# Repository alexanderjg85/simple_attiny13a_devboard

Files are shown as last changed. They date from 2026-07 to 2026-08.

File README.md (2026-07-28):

# simple_attiny13a_devboard
A simple development board with an LED and GPIOs on Pin header, includes also ISP Header, Power supply with screw terminal.

## Project Structure
- **/hardware**: Contains the KiCad schematic and PCB layout files.
- **/firmware**: Contains the Microchip Studio 7 C/ASM source code.

## Programming Notes
- Designed for the **ATtiny13A** microcontroller.
- Programmed using **Atmel Studio 7** and an **AVRISP mkII** programmer.
- *Note:* The board requires an external power supply (e.g., 5V) during programming, as the AVRISP mkII does not supply power to the target VCC.

## License / Lizenz

This project is dual-licensed / Dieses Projekt ist dual-lizenziert:

* **Hardware (Schematic, PCB Layout):** Licensed under the [CERN Open Hardware Licence Version 2 - Permissive (CERN-OHL-P)](LICENSE_HARDWARE.md).
* **Software (Firmware, Example Code):** Licensed under the [MIT License](LICENSE).

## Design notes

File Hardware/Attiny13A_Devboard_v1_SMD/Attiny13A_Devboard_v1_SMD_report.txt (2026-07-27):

PCB statistics report
=====================
- Date: Mon 27 Jul 2026 23:36:47 CEST
- Project: Attiny13A_Devboard_v1_SMD
- Board name: Attiny13A_Devboard_v1_SMD

Board
-----
- Width: 48.0000 mm
- Height: 24.0000 mm
- Area: 1152.00 mm²
- Front copper area: 191.524 mm²
- Back copper area: 1065.117 mm²
- Min track clearance: 0.2000 mm
- Min track width: 0.3000 mm
- Min drill diameter: 0.4500 mm
- Board stackup thickness: 1.6000 mm

- Front footprint area: 438.677 mm²
- Back footprint area: 58.296 mm²
- Front component density: 38.08 %
- Back component density: 5.06 %
Pads
----
- Through hole: 14
- SMD: 33
- Connector: 0
- NPTH: 0
- Castellated: 0
- Press-fit: 0

Vias
----
- Through vias: 19
- Blind vias: 0
- Buried vias: 0
- Micro vias: 0

Components
----------

| | Front Side | Back Side | Total |
|---|---|---|---|
|THT: | 3 | 0 | 3 |
|SMD: | 8 | 0 | 8 |
|Unspecified:  | 9 | 0 | 9 |
|Total: | 20 | 0 | 20 |

Drill holes
-----------

| Count | Shape | X Size | Y Size | Plated | Via/Pad | Start Layer | Stop Layer |
|---|---|---|---|---|---|---|---|
| 12 | Round | 1.0000 mm | 1.0000 mm | PTH | Pad | F.Cu | B.Cu |
| 11 | Round | 0.5000 mm | 0.5000 mm | PTH | Via | F.Cu | B.Cu |
| 8 | Round | 0.4500 mm | 0.4500 mm | PTH | Via | F.Cu | B.Cu |
| 2 | Round | 1.3000 mm | 1.3000 mm | PTH | Pad | F.Cu | B.Cu |

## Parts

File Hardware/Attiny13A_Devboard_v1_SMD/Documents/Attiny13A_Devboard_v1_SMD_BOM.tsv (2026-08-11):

Reference | Qty | Value | Spec | Package | MFR PN
C1 | 1 | 10 uF | 20% 16V | 1206
C2 | 1 | 100 nF | 20% 16V | 1206
D1 | 1 | SS14 | 0.5A 30 V | SMA
D2 | 1 | RED | LED RED | 1206
J1 | 1 | Screw_Terminal_01x02 | Horizontal | 5.08mm 1x2
J2 | 1 | ISP-6 | Male / THT/ Vertical | 2.54 mm 1x3
J3 | 1 | Conn_01x06_Pin | Male / THT/ Vertical | 2.54 mm 1x6
R1 | 1 | 470 | 1% 125 mW | 1206
R2 | 1 | 10k | 1% 125 mW | 1206
SW1 | 1 | SW_RESET | H=4.5mm Tactile | 4.5 x 4.5 SMD | SWT0210-045026GSA
U1 | 1 | ATtiny13A-SS | 8-Bit AVR 20 Mhz | SOIC-8 | ATTINY13A-SSU

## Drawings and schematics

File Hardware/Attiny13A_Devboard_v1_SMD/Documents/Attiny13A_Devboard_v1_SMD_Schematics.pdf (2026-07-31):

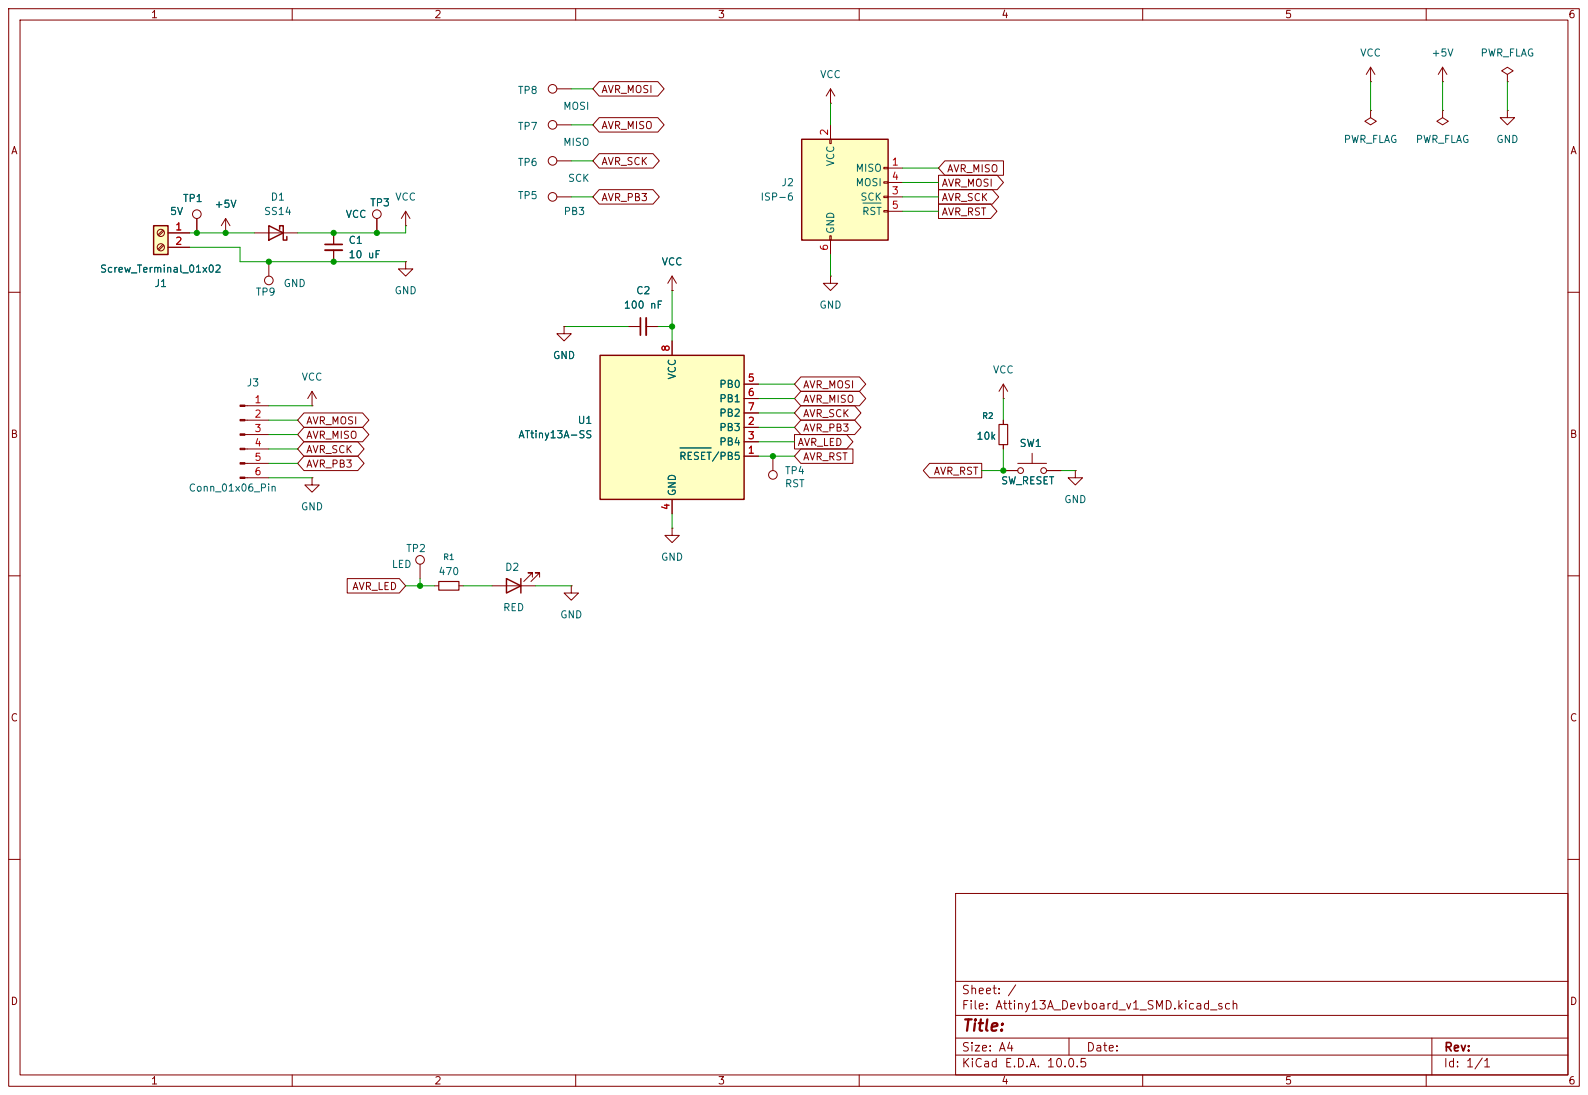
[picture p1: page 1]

Size: A4 | Rev:
KiCad E.D.A. 10.0.5 | Id: 1/1

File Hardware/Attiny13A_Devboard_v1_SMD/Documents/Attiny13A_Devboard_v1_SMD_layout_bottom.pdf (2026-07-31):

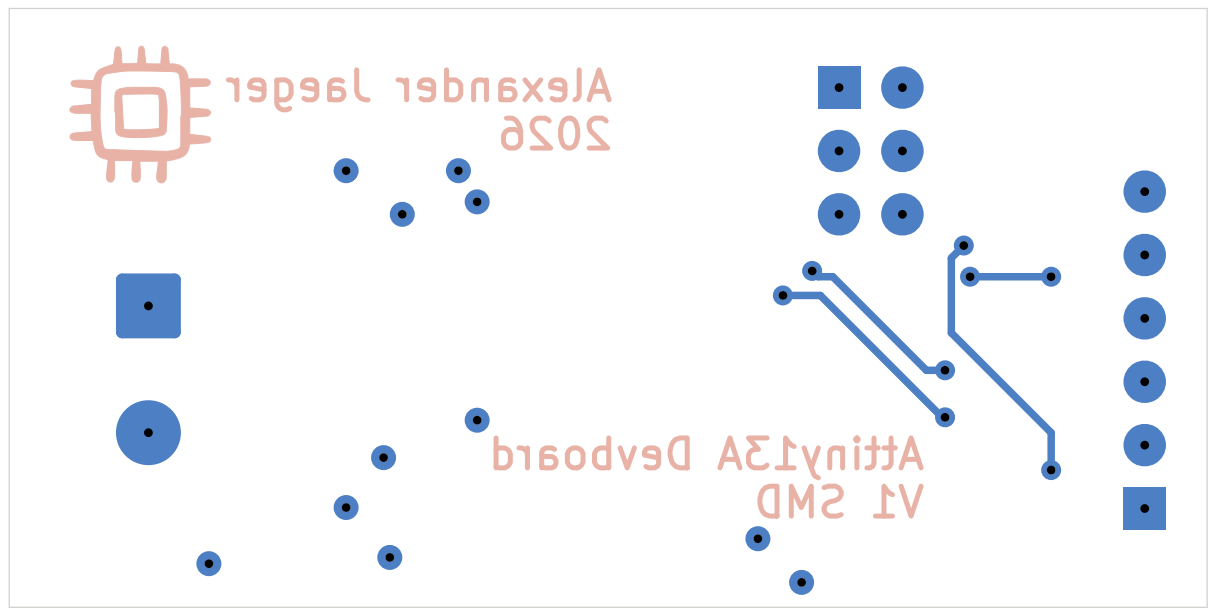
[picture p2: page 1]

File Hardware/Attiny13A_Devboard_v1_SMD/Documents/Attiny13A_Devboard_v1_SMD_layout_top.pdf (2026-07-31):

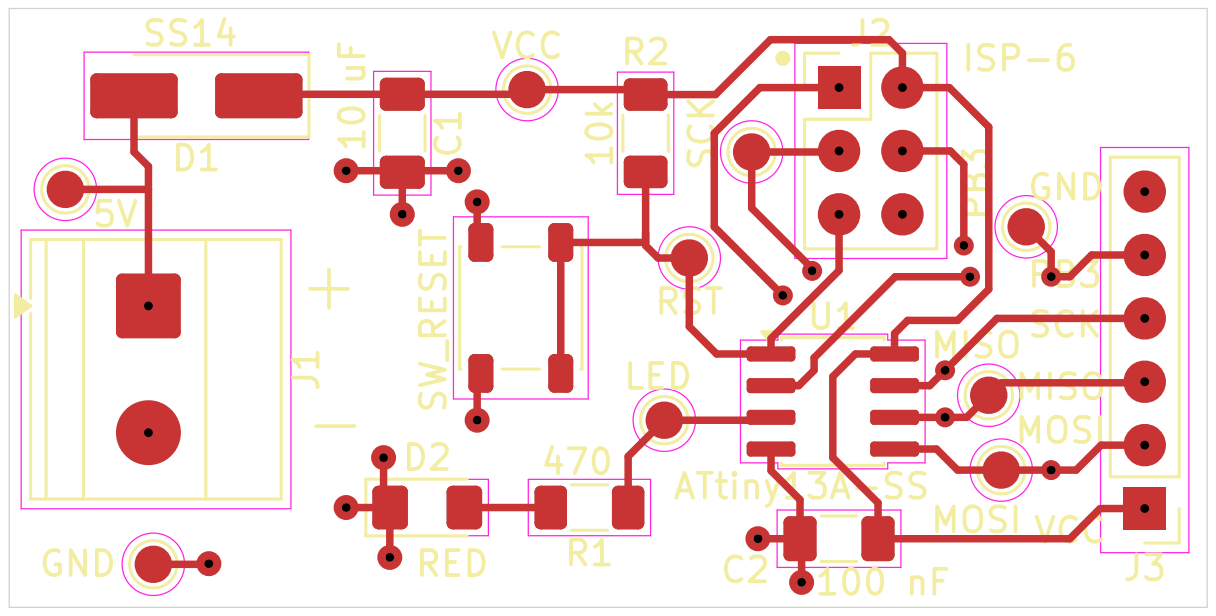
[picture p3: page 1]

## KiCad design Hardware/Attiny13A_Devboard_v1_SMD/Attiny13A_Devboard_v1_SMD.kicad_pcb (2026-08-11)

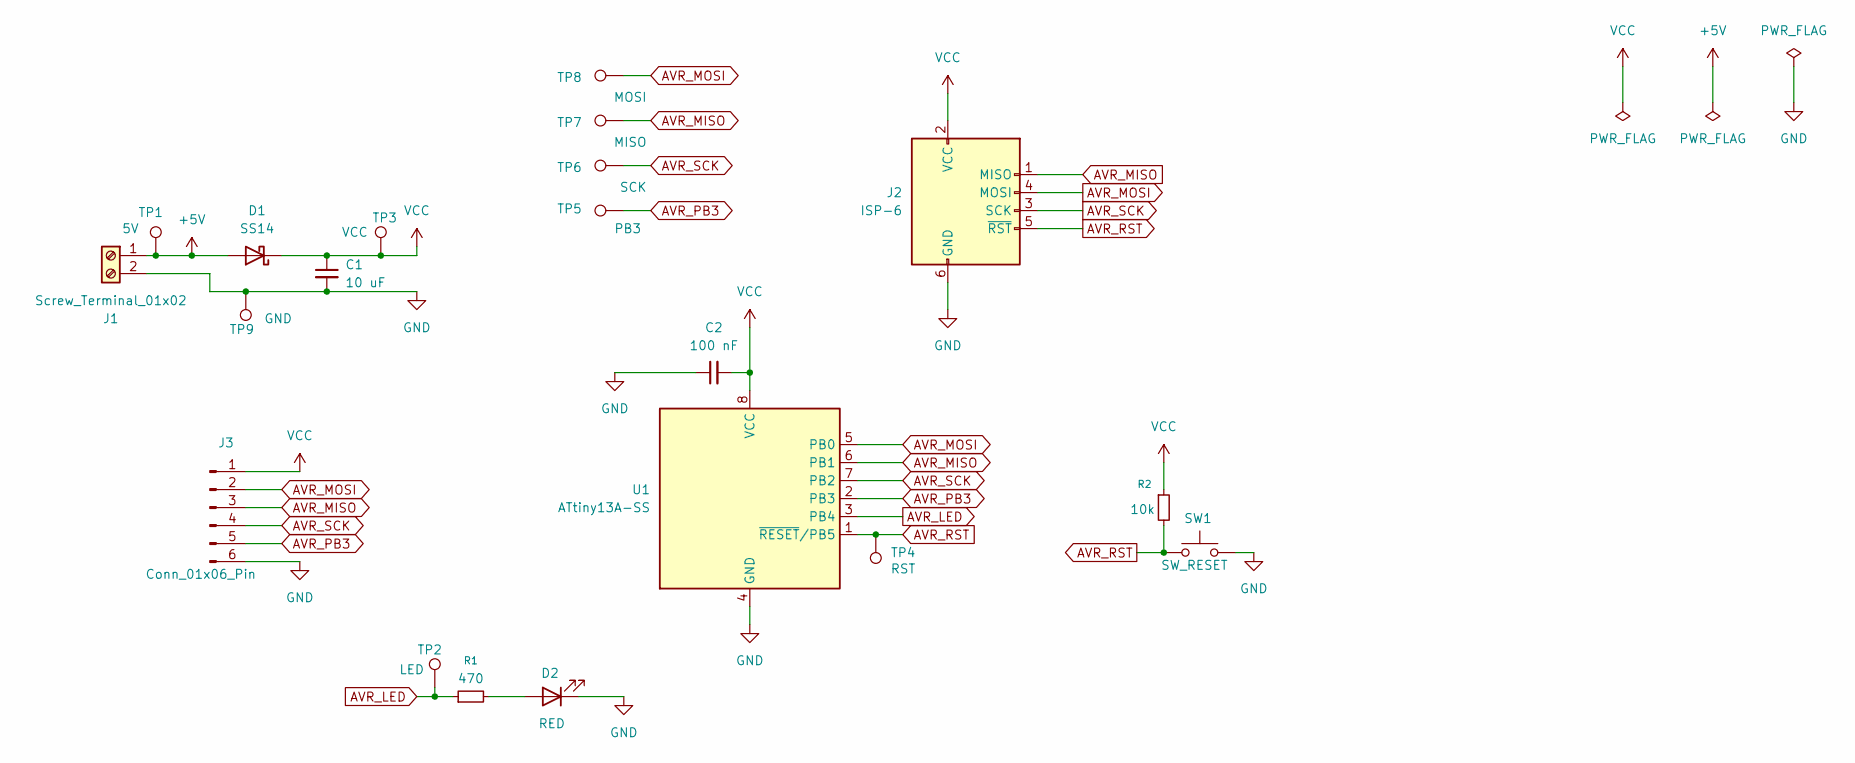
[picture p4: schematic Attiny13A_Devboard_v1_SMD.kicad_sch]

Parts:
C1: 10 uF; C_1206_3216Metric_Pad1.33x1.80mm_HandSolder
C2: 100 nF; C_1206_3216Metric_Pad1.33x1.80mm_HandSolder
D1: SS14; D_SMA_Handsoldering
D2: RED; LED_1206_3216Metric_Pad1.42x1.75mm_HandSolder
J1: Screw_Terminal_01x02; TerminalBlock_Phoenix_MKDS-1,5-2-5.08_1x02_P5.08mm_Horizont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
J2: ISP-6; PinHeader_2x03_P2.54mm_Vertical
J3: Conn_01x06_Pin; PinHeader_1x06_P2.54mm_Vertical
R1: 470; R_1206_3216Metric_Pad1.30x1.75mm_HandSolder
R2: 10k; R_1206_3216Metric_Pad1.30x1.75mm_HandSolder
SW1: SW_RESET; SW_SPST_PTS647_Sx38_Handsolder; MFR PN SWT0210-045026GSA
TP1: 5V; TestPoint_Pad_D1.5mm
TP2: LED; TestPoint_Pad_D1.5mm
TP3: VCC; TestPoint_Pad_D1.5mm
TP4: RST; TestPoint_Pad_D1.5mm
TP5: PB3; TestPoint_Pad_D1.5mm
TP6: SCK; TestPoint_Pad_D1.5mm
TP7: MISO; TestPoint_Pad_D1.5mm
TP8: MOSI; TestPoint_Pad_D1.5mm
TP9: GND; TestPoint_Pad_D1.5mm
U1: ATtiny13A-SS; SOIC-8_3.9x4.9mm_P1.27mm; MFR PN ATTINY13A-SSU

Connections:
+5V: D1.2 (A), J1.1, TP1.1 (1_1)
AVR_LED: R1.1, TP2.1 (1_1), U1.3 (PB4)
AVR_MISO: J2.1 (MISO), J3.3, TP7.1 (1_1), U1.6 (PB1)
AVR_MOSI: J2.4 (MOSI), J3.2, TP8.1 (1_1), U1.5 (PB0)
AVR_PB3: J3.5, TP5.1 (1_1), U1.2 (PB3)
AVR_RST: J2.5 (~RST), R2.2, SW1.1, TP4.1 (1_1), U1.1 (~RESET/PB5)
AVR_SCK: J2.3 (SCK), J3.4, TP6.1 (1_1), U1.7 (PB2)
GND: C1.2, C2.1, D2.1 (K), J1.2, J2.6 (GND), J3.6, SW1.2, TP9.1 (1_1), U1.4 (GND)
unnamed: D2.2 (A), R1.2
VCC: C1.1, C2.2, D1.1 (K), J2.2 (VCC), J3.1, R2.1, TP3.1 (1_1), U1.8 (VCC)

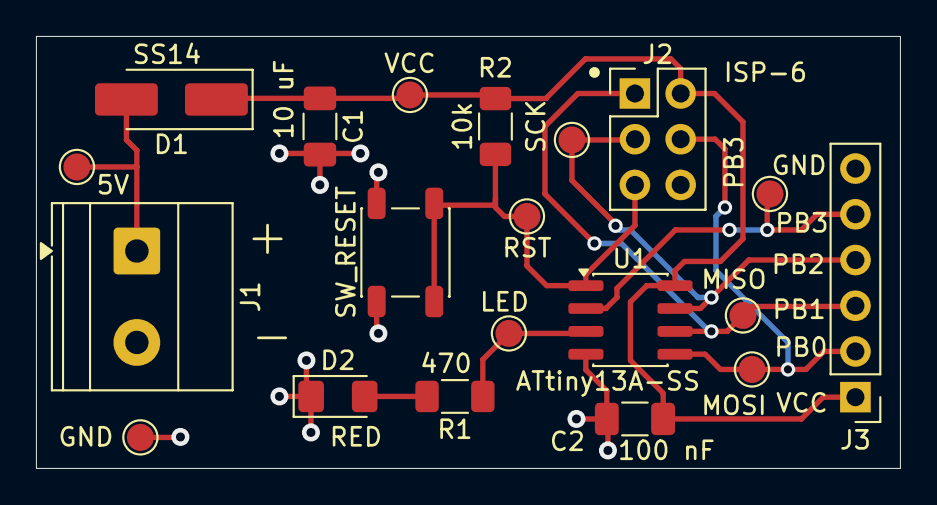
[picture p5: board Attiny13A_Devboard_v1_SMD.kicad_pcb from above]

Board: 2 copper layers, 48.0 x 24.0 mm, 20 parts (0 on the bottom side), 10 nets.

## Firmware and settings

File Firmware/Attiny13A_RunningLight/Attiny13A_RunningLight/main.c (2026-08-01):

/*
 * Attiny13A_Blinky_4_LEDS.c
 *
 * Created: 09.07.2026 18:42:30
 * Author : alexa
 */

#define F_CPU 1200000UL  ///< 9,6 Mhz internal CLK, DIV 8, not changed


#include <avr/io.h>
#include <util/delay.h>
#include "main.h"
#include "gpio_functions.h"


#define LED_BOARD PORTB4
#define LED_DELAY_ms 500	///< time a LED lights before switched to the next

void init(void);

int main(void)
{
    init();    
    while (1) 
    {
		set_PortPin(LED_BOARD);
		clear_PortPin(PORTB3);
		_delay_ms(LED_DELAY_ms);
		
		set_PortPin(PORTB0);
		clear_PortPin(LED_BOARD);
		_delay_ms(LED_DELAY_ms);
		
		set_PortPin(PORTB1);
		clear_PortPin(PORTB0);
		_delay_ms(LED_DELAY_ms);
		
		set_PortPin(PORTB2);
		clear_PortPin(PORTB1);
		_delay_ms(LED_DELAY_ms);
		
		set_PortPin(PORTB3);
		clear_PortPin(PORTB2);
		_delay_ms(LED_DELAY_ms);
    }
}

void init(void)
{
	DDRB = 0x0;		///< all pins as Input
	DDRB |= (1 << LED_BOARD) | (1 << PORTB0) | (1 << PORTB1) | (1 << PORTB2) | (1 << PORTB3);	///< set the 4 led ports + onboard led  as output
	PORTB = 0x0;	///< set all pins low
}

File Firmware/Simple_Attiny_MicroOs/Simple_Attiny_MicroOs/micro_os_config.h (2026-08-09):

/*
 * micro_os_config.h
 *
 * Created: 01.08.2026 18:52:23
 *  Author: alexa
 * Provides configuration and functions the MicroOS Core Configuration and Initialization
 */ 


#ifndef MICRO_OS_CONFIG_H_
#define MICRO_OS_CONFIG_H_

#include "custom_types.h"
#include <assert.h>


///< Helper Macro to print values that are define by a #define in an assert output string
#define STR_HELPER(x) #x
#define TO_STRING(x) STR_HELPER(x)

///< Defines events a task may react to
typedef enum {
	TASK_EVENT_INIT,
	TASK_EVENT_LOOP
} TaskEvent;

///< defines a typedef for function pointers with one argument used by the OS
typedef void (*TaskFunc)(TaskEvent event);

#define ms_PER_min 60000	///< number of ms in a minute
#define SCHEDULER_PERIOD_MS ms_PER_min	///< Time until the systicktimer starts counting from zero again
#define MAX_TASKS 6	///< maximum allowed number of taks, don't change
#define TASK_CNT 6	///< actual used number of tasks, change to adjust the os, set a value from 1 to 6
static_assert(TASK_CNT<= MAX_TASKS, "No more than " TO_STRING(MAX_TASKS) " tasks are supported!");
#define MAX_TASK_INTERVALL_ms 200	///< maximum task interval the OS supports

///< definition of the struct that contains the task and task information during runtime
struct scheduler_event
{
	uint8 interval_ms;
	uint8 offset_ms;	
	TaskFunc task_main;
	bool triggered;
};

///< type definition of the struct that contains the task and task information during initialization
typedef struct {
	uint8 interval_ms;
	uint8 offset_ms;
	TaskFunc task_main;
} TaskConfig;

///< enum that defines the interval of all tasks, change this values to adjust the operating system
///< if number of tasks is less than the maximum of 6, the unused tasks still need a valid interval otherwise the assert will fail
enum TASK_INTERVALS {
	TASK_1_INTERVAL = 200,
	TASK_2_INTERVAL = 200,
	TASK_3_INTERVAL = 100,
	TASK_4_INTERVAL = 100,
	TASK_5_INTERVAL = 100,
	TASK_6_INTERVAL = 100
};
///< make sure task interval are not set to a number that isn't a divisor of the scheduler period, otherwise the tasks will jitter
static_assert((SCHEDULER_PERIOD_MS % TASK_1_INTERVAL) == 0, "Task 1 Interval invalid!");
static_assert((SCHEDULER_PERIOD_MS % TASK_2_INTERVAL) == 0, "Task 2 Interval invalid!");
static_assert((SCHEDULER_PERIOD_MS % TASK_3_INTERVAL) == 0, "Task 3 Interval invalid!");
static_assert((SCHEDULER_PERIOD_MS % TASK_4_INTERVAL) == 0, "Task 4 Interval invalid!");
static_assert((SCHEDULER_PERIOD_MS % TASK_5_INTERVAL) == 0, "Task 5 Interval invalid!");
static_assert((SCHEDULER_PERIOD_MS % TASK_6_INTERVAL) == 0, "Task 6 Interval invalid!");

///< enum that defines the offsets of all tasks, change this values to adjust the operating system
///< if number of tasks is less than the maximum of 6, the unused tasks still need a valid offset otherwise the assert will fail
enum TASK_OFFSETS {
	TASK_1_OFFSET = 0,
	TASK_2_OFFSET = 100,
	TASK_3_OFFSET = 10,
	TASK_4_OFFSET = 20,
	TASK_5_OFFSET = 30,
	TASK_6_OFFSET = 40
};
///< make sure task offsets don't exceed the maximum task interval
static_assert((TASK_1_OFFSET <= MAX_TASK_INTERVALL_ms), "Task 1 Offset too large!");
static_assert((TASK_2_OFFSET <= MAX_TASK_INTERVALL_ms), "Task 2 Offset too large!");
static_assert((TASK_3_OFFSET <= MAX_TASK_INTERVALL_ms), "Task 3 Offset too large!");
static_assert((TASK_4_OFFSET <= MAX_TASK_INTERVALL_ms), "Task 4 Offset too large!");
static_assert((TASK_5_OFFSET <= MAX_TASK_INTERVALL_ms), "Task 5 Offset too large!");
static_assert((TASK_6_OFFSET <= MAX_TASK_INTERVALL_ms), "Task 6 Offset too large!");


///< define the task functions
void task1_main(TaskEvent event);
void task2_main(TaskEvent event);
void task3_main(TaskEvent event);
void task4_main(TaskEvent event);
void task5_main(TaskEvent event);
void task6_main(TaskEvent event);

///< array that will be used during startup to initialize all the task, don't change, use the enums above to adjust the OS
const TaskConfig TASK_CONFIG[MAX_TASKS] PROGMEM = {
	{TASK_1_INTERVAL, TASK_1_OFFSET, task1_main}, {TASK_2_INTERVAL, TASK_2_OFFSET, task2_main}, {TASK_3_INTERVAL, TASK_3_OFFSET, task3_main},
	{TASK_4_INTERVAL, TASK_4_OFFSET, task4_main}, {TASK_5_INTERVAL, TASK_5_OFFSET, task5_main}, {TASK_6_INTERVAL, TASK_6_OFFSET, task6_main}
};

///< create the struct that contains the tasks
struct scheduler_event events[TASK_CNT];

#endif /* MICRO_OS_CONFIG_H_ */

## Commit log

2026-07-25 Added Kicad Project files for Attiny13A Dev Board SMD Edition
    [Attiny13A_Devboard_v1_SMD.kicad_pcb, Attiny13A_Devboard_v1_SMD.kicad_sch]
2026-07-25 Attiny13A Dev Board SMD - Finished Schematics
    [Attiny13A_Devboard_v1_SMD.kicad_sch]
2026-07-26 Attiny13A Dev Board SMD - Added Testpoints to Schematics
    [Attiny13A_Devboard_v1_SMD.kicad_sch]
2026-07-26 Attiny13A Dev Board SMD - Added Testpoints Footprint to Schematics
    [Attiny13A_Devboard_v1_SMD.kicad_sch]
2026-07-26 Attiny13A Dev Board SMD - Added JLCPCB Designrules
    [Attiny13A_Devboard_v1_SMD.kicad_pcb]
2026-07-26 Attiny13A Dev Board SMD - Layout - Initial Placement done
    [Attiny13A_Devboard_v1_SMD.kicad_pcb, Attiny13A_Devboard_v1_SMD.kicad_sch]
2026-07-26 Attiny13A Dev Board SMD - Layout - Initial Routing done
    [Attiny13A_Devboard_v1_SMD.kicad_pcb]
2026-07-27 Attiny13A Dev Board SMD - Layout - Optimized Silk Screen
    [Attiny13A_Devboard_v1_SMD.kicad_pcb, Attiny13A_Devboard_v1_SMD.kicad_sch]
2026-07-27 Attiny13A Dev Board SMD - Created Gerber Files
    [Attiny13A_Devboard_v1_SMD-B_Cu.gbr, Attiny13A_Devboard_v1_SMD-B_Mask.gbr, Attiny13A_Devboard_v1_SMD-B_Paste.gbr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]
2026-07-30 Attiny13A Dev Board SMD - Schematics - Added Part Properties
    [Attiny13A_Devboard_v1_SMD.kicad_sch]
2026-07-31 Attiny13A Dev Board SMD - Schematics - Added Schematic and Board Layout PDFs
2026-07-31 ttiny13A Dev Board SMD - Schematics - Added BOM
    [Attiny13A_Devboard_v1_SMD_BOM.tsv]
2026-07-31 Attiny13A Dev Board SMD - Schematics - Added Datasheets
2026-08-01 Attiny13A Dev Board SMD - Firmware - Added Blinky LED and Running Light Example
2026-08-09 Attiny13A Dev Board SMD - Firmware - Added Simple Attiny Micro Os
2026-08-11 Attiny13A Dev Board SMD - Updated Reset Switch Footprint for better Handsoldering - Optimized Silk Screen
    [Attiny13A_Devboard_v1_SMD.kicad_pcb, Attiny13A_Devboard_v1_SMD.kicad_sch]
2026-08-11 Attiny13A Dev Board SMD - Schematics - Updated BOM
    [Attiny13A_Devboard_v1_SMD_BOM.tsv]
